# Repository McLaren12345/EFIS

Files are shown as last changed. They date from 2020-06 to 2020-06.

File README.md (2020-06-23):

# EFIS
### Introduction
A STM32 based Primary Flight Display with QT based PC software indicator. Contain PCB files, STM32 project files, QT project files and 3D print models.

本项目为基于STM32的微型姿态仪，包含PCB文件，STM32工程文件，QT工程文件与3D打印外壳文件。

采用陀螺仪传感器MPU6050，气压式高度计BMP180，程序可以显示模块当前的六轴传感器数据与海拔高度，空速与垂直速度等采用模拟积分方法计算求得(也就是惯性导航)。BMP180气压数据采用一阶卡尔曼滤波方法进行平滑。通讯采用NRF21L01无线模块传输，PCB中未画出，仅保留了与模块的接口。

QT部分基于开源项目修改；https://sourceforge.net/projects/qfi/

### Images
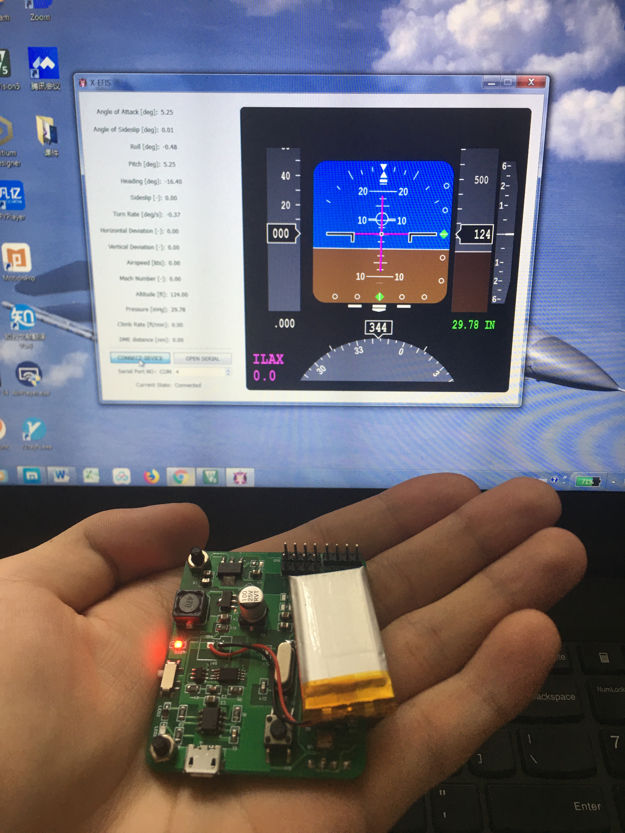
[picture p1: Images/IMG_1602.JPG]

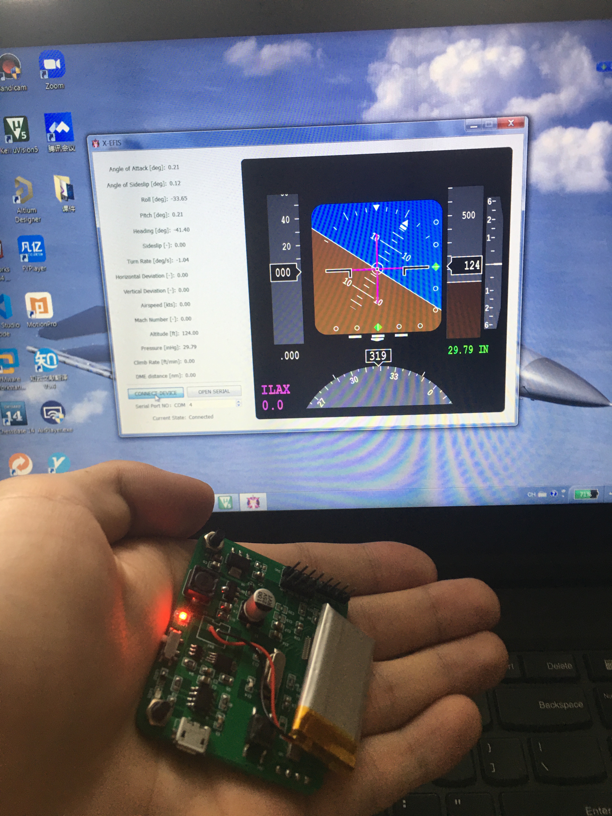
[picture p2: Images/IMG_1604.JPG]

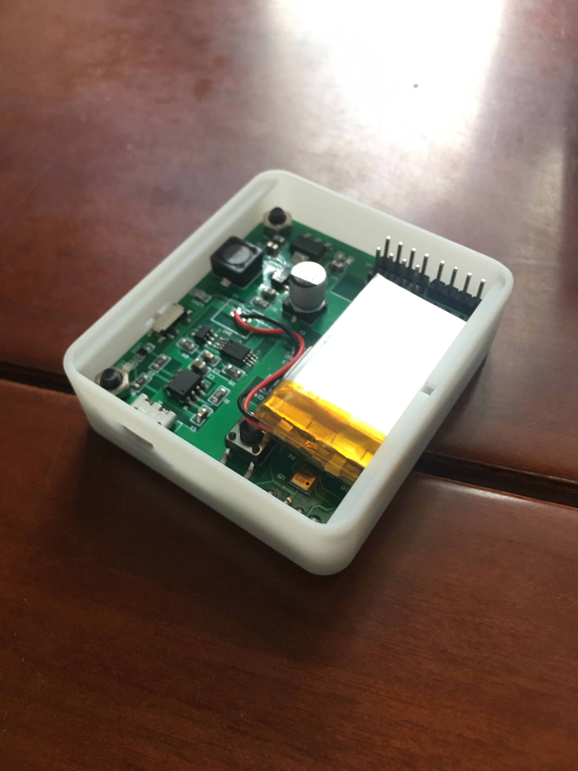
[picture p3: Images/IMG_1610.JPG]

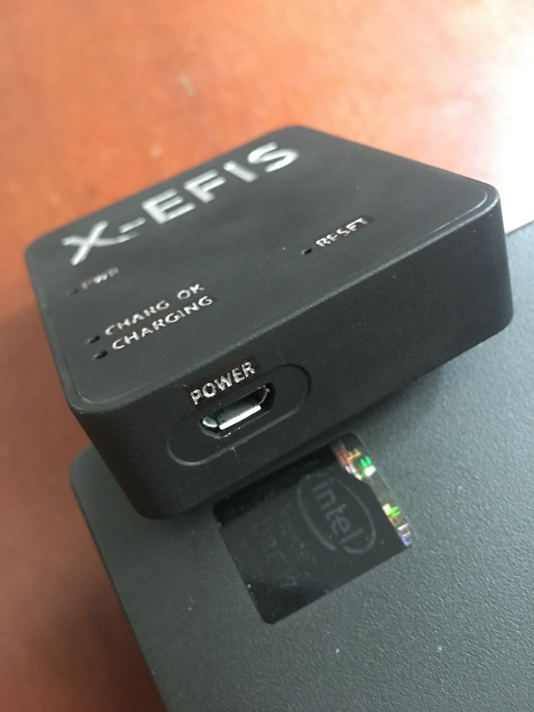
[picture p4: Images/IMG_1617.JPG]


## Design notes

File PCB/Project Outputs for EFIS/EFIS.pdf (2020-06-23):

Comment | Description | Designator | Footprint | LibRef | Quantity
HDR-1X2 | 2P接插件 | BAT | XH2.54-LI-2P | Header 2 | 1
10uf | 贴片电容 | C1, C3, C5, C7, C10, C11, C15, C16, C17, C18, C19, C20 | C 0805_L | C | 12
100uf | 贴片电容 | C2 | C 0805_L | C | 1
0.1uf | 贴片电容 | C4, C6, C8 | C 0805_L | C | 3
104 | 贴片电容 | C9, C12 | C 0805_L | C | 2
22pf | 贴片电容 | C13, C14 | C 0805_L | C | 2
B5919WS | 肖特基二极管 | D1 | SOD-323 | 1N5819 | 1
100uF/16V | 贴片电解电容 | E1 | CM D(6.3*5.4) | CE_SMD | 1
TP4056 | 外置EEPROM | IC1 | SOP8_L | 24Cxx | 1
HDR-1X4 | 4P接插件 | JP2, JP4, JP5, SWD | HDR2.54-LI-4P | Header 4 | 4
47uH | 功率屏蔽电感 | L1 | CDRH73 | L-CDRH | 1
红色 | 贴片LED | LED1, LED3 | LED 0603R | LED-SMD | 2
绿色 | 贴片LED | LED2 | LED 0603G | LED-SMD | 1
1.2K | 贴片电阻 | R1 | R 0805_L | R | 1
1K | 贴片电阻 | R2, R3, R5, R6, R11 | R 0805_L | R | 5
100R | 贴片电阻 | R4 | R 0805_L | R | 1
10R | 贴片电阻 | R7 | R 0805_L | R | 1
10K | 贴片电阻 | R8, R9, R10 | R 0805_L | R | 3
SS-12F23 | 1路波动开关 | S1 | MSK-12C01-07 | SSW-1P | 1
6x6x5 | 贴片6x6轻触开 关 | SW1 | TSW SMD-6*6*5 | TSW SMD-6x6 | 1
STM32F103C8T 6 | STM32 ARM-based 32-bit MCU Performance Line with 64 kB Flash, 20 kB Internal RAM, -40 to +85癈 Temperature, 48-Pin LQFP, Tray | U1 | LQFP48_N | STM32F103C8T 6 | 1
DW01 | 锂电池过流保护 IC | U2 | SOT23-6N | DW01 | 1
GS8205A | N沟道增强型功 率场效应管 | U3 | SSOP8_N | GS8205A | 1
MPU6050 | 三轴加速度+三 轴陀螺仪 | U4 | QFN_24 | MPU6050 | 1
BMP180 | | U5 | LGA7 | BMP180 | 1
USB-5P | 微型USB母座 | USB1 | USB-MICRO_A | USB-5P | 1
AMS1117-3V3 | 三端稳压芯片 | V1 | SOT223_N | AMS1117 | 1
CE8301 | LDO线性稳压芯 片 | V2 | SOT89_N | HT71xx | 1
8MHz | 2脚无源脚晶振 | X1 | OSC HC-49SMD | XTAL-2P | 1

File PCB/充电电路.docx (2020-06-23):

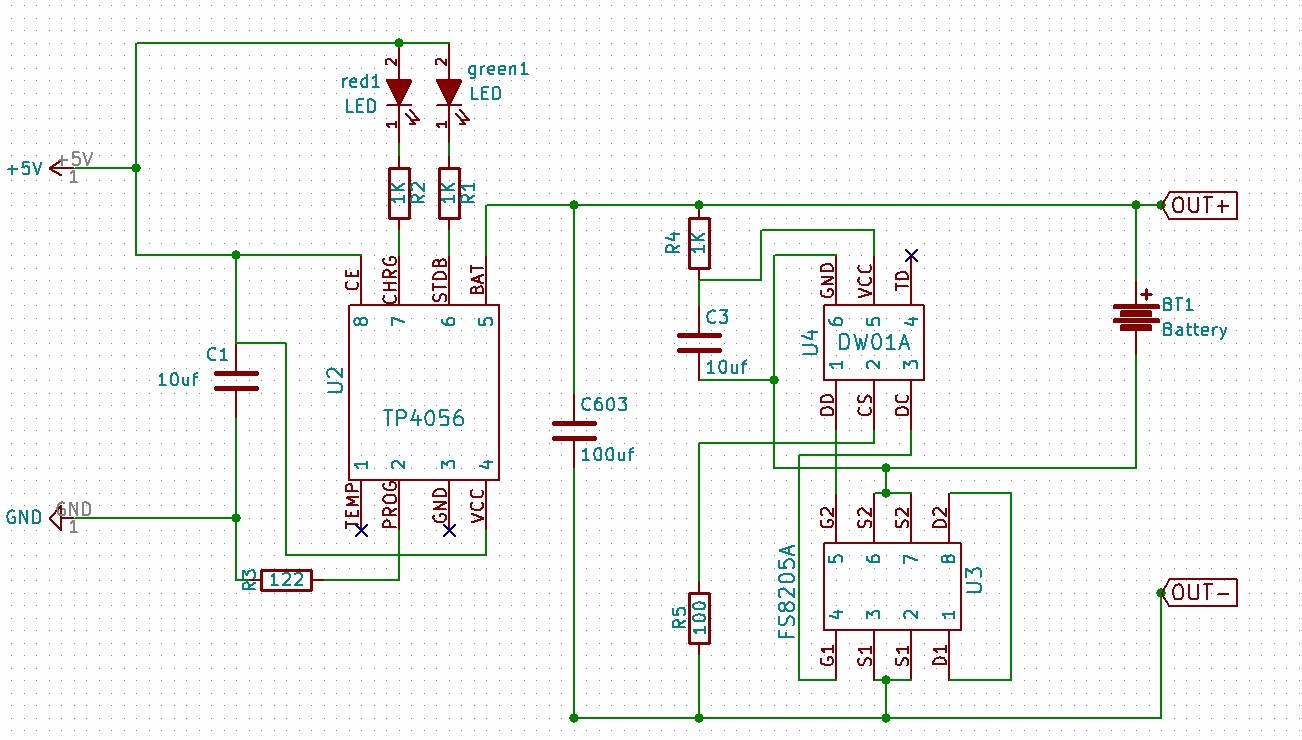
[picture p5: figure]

OUT-要和GND连在一起。R4和R5的值反了，R4是100，R5是1K。

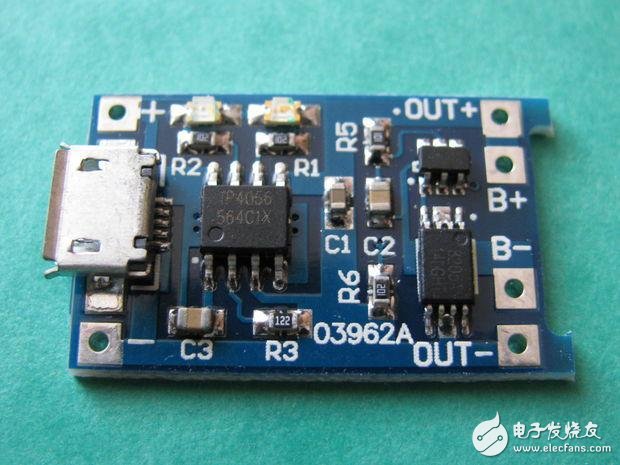
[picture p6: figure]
æ æ æ æ ä½ å ¶ä½ ä¸ ä¸ªç µæ± ä¿ æ ¤ç ¾æ ¿
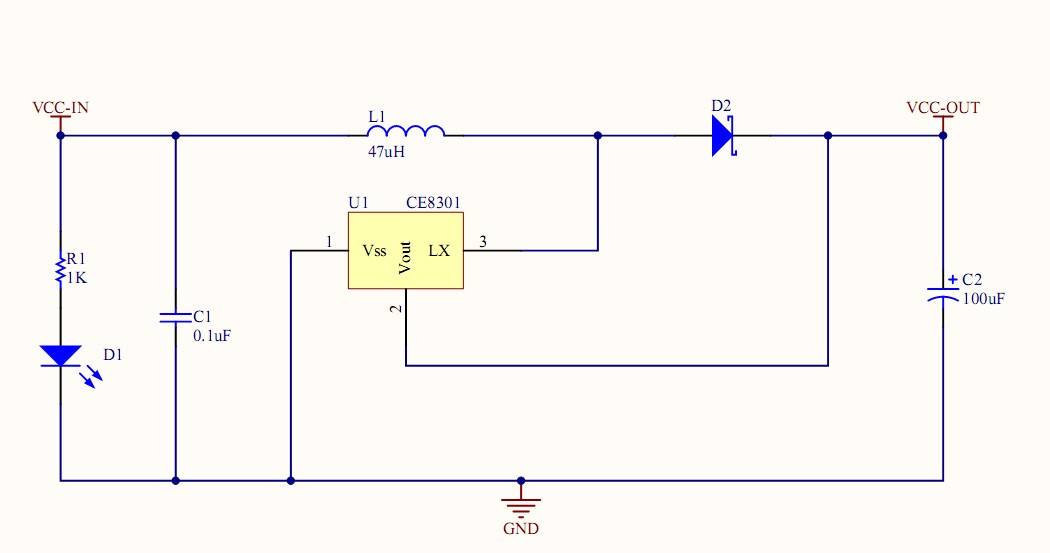
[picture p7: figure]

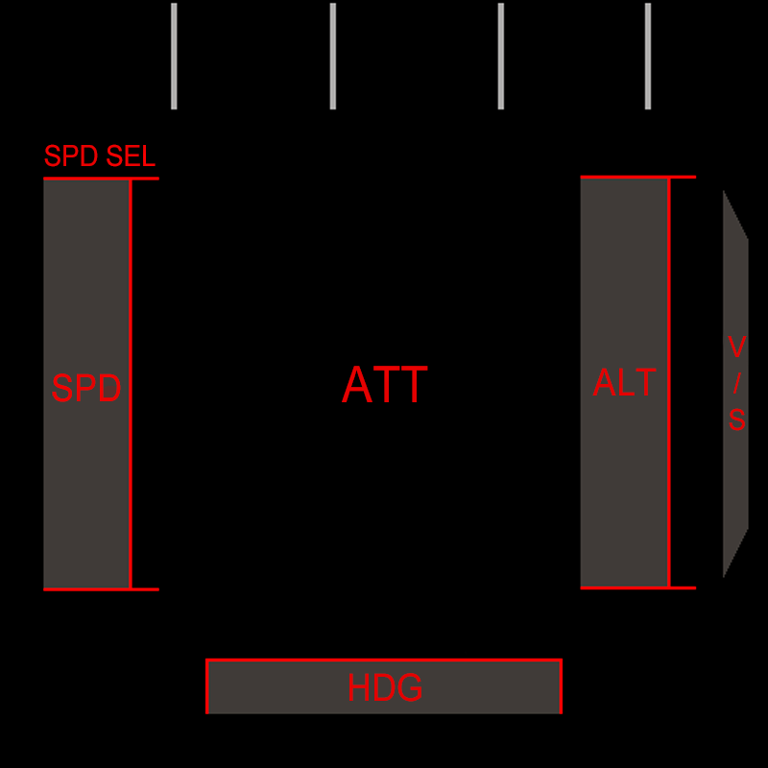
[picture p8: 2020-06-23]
QT/images/pfd/align_pfd-1.png

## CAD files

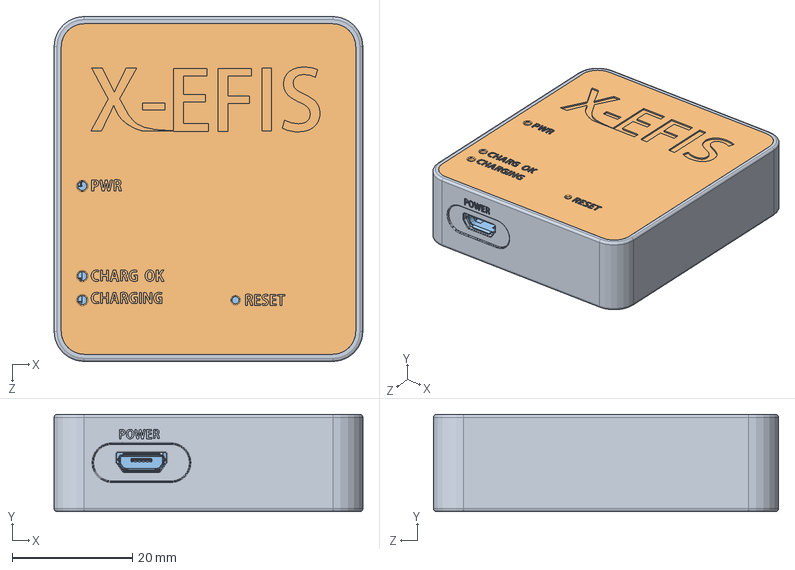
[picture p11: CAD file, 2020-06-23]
EFIS 3D Cover/BOX.SLDASM
51.4 x 16.2 x 57.4 mm
CoverBox
BoxTop
PCB1

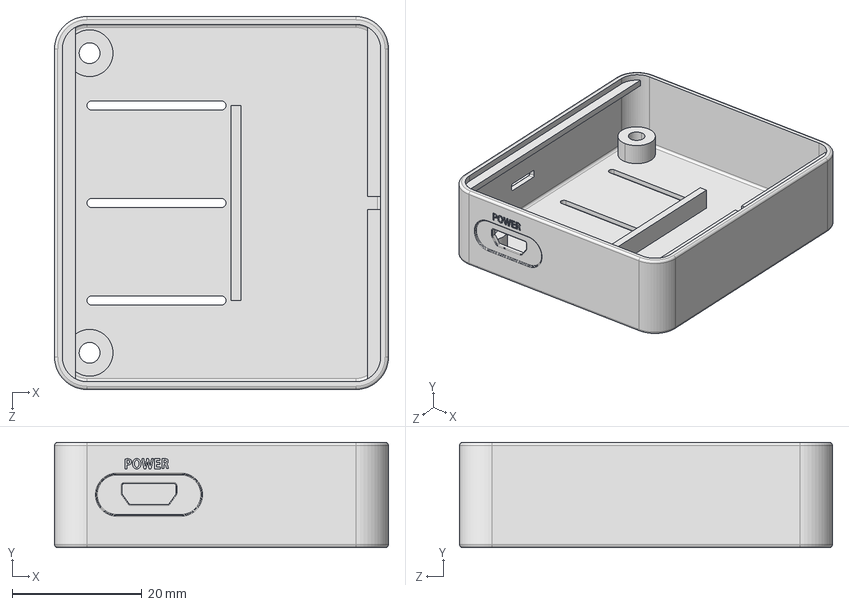
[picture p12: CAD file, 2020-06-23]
EFIS 3D Cover/CoverBox.STEP
51.4 x 16.2 x 57.4 mm

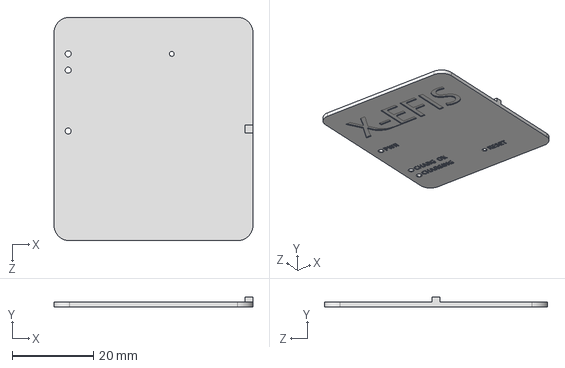
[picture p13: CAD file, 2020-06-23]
EFIS 3D Cover/BoxTop.STEP
49.0 x 2.40 x 55.0 mm

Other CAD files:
EFIS 3D Cover/BoxTop.SLDPRT
EFIS 3D Cover/BoxTop.STL
EFIS 3D Cover/CoverBox.SLDPRT
EFIS 3D Cover/CoverBox.STL

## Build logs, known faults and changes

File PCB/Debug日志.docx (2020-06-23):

Debug日志

1.I2C总线需要上拉电阻，电阻的阻值根据通讯速率选取，如不加数据返回一直为0

2.芯片一直复位：

2.1软件问题：F103芯片的头文件有3种，对应高中小三种flash容量，选错头文件编译出来的程序会跑飞激发硬件看门狗，同样，keil工程的配置也要做相应修改，同时芯片擦写算法尽量选择MDK CORE的算法

2.2硬件问题：1.复位电容击穿，现象为电容的容值为无穷大，相当于电阻为0，直接与GND短接2.助焊膏会吸潮，没有擦干净会导致莫名其妙的问题，应使用酒精等溶剂洗板

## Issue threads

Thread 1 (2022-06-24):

No program X-EFIS

brightproject, 2022-06-24:
Please tell me how to install your code on the stm32 board, as an example F103C8T6
Where did the gui interface x-efis go?
I wanted to try your project, but I can't find the "entry point" to it.

McLaren12345, 2022-06-24:
The STM32 Project is based on Keil IDE, and the project file is located at STM32/USER/MPU6050.uvprojx.
The QT based GUI project file is located at QT/src/example.pro.
It can be easy if your computer have installed these IDE or you need to import the project to other IDE by yourself.

brightproject, 2022-06-24:
There is main.c file?

McLaren12345, 2022-06-25:
yes, the main.c file is also in that path.

------------------ Original ------------------
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

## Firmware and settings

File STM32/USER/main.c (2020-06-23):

#include "led.h"
#include "delay.h"
#include "key.h"
#include "sys.h"
#include "lcd.h"
#include "usart.h"
#include "mpu6050.h"
#include "bmp180.h"
#include "usmart.h"   
#include "inv_mpu.h"
#include "inv_mpu_dmp_motion_driver.h" 

 
/************************************************
 ALIENTEK战舰STM32开发板实验32
 MPU6050六轴传感器 实验
 技术支持：www.openedv.com
 淘宝店铺：http://eboard.taobao.com 
 关注微信公众平台微信号："正点原子"，免费获取STM32资料。
 广州市星翼电子科技有限公司  
 作者：正点原子 @ALIENTEK
************************************************/


//串口1发送1个字符 
//c:要发送的字符
void usart1_send_char(u8 c)
{   	
	while(USART_GetFlagStatus(USART2,USART_FLAG_TC)==RESET); //循环发送,直到发送完毕   
	USART_SendData(USART2,c);  
} 
//传送数据给匿名四轴上位机软件(V2.6版本)
//fun:功能字. 0XA0~0XAF
//data:数据缓存区,最多28字节!!
//len:data区有效数据个数
void usart1_niming_report(u8 fun,u8*data,u8 len)
{
	u8 send_buf[31];
	u8 i;
	if(len>28)return;	//最多28字节数据 
	//send_buf[len+3]=0;	//校验数置零
	send_buf[0]=0X88;	//帧头
	send_buf[1]=fun;	//功能字
	send_buf[2]=len;	//数据长度
	for(i=0;i<len;i++)send_buf[3+i]=data[i];			//复制数据
	//for(i=0;i<len+3;i++)send_buf[len+3]+=send_buf[i];	//计算校验和	
	for(i=0;i<len+3;i++)usart1_send_char(send_buf[i]);	//发送数据到串口1 
}
//发送加速度传感器数据和陀螺仪数据
//aacx,aacy,aacz:x,y,z三个方向上面的加速度值
//gyrox,gyroy,gyroz:x,y,z三个方向上面的陀螺仪值
void mpu6050_send_data(short aacx,short aacy,short aacz,short gyrox,short gyroy,short gyroz)
{
	u8 tbuf[12]; 
	tbuf[0]=(aacx>>8)&0XFF;
	tbuf[1]=aacx&0XFF;
	tbuf[2]=(aacy>>8)&0XFF;
	tbuf[3]=aacy&0XFF;
	tbuf[4]=(aacz>>8)&0XFF;
	tbuf[5]=aacz&0XFF; 
	tbuf[6]=(gyrox>>8)&0XFF;
	tbuf[7]=gyrox&0XFF;
	tbuf[8]=(gyroy>>8)&0XFF;
	tbuf[9]=gyroy&0XFF;
	tbuf[10]=(gyroz>>8)&0XFF;
	tbuf[11]=gyroz&0XFF;
	usart1_niming_report(0XA1,tbuf,12);//自定义帧,0XA1
}	
//通过串口1上报结算后的姿态数据给电脑
//aacx,aacy,aacz:x,y,z三个方向上面的加速度值
//gyrox,gyroy,gyroz:x,y,z三个方向上面的陀螺仪值
//roll:横滚角.单位0.01度。 -18000 -> 18000 对应 -180.00  ->  180.00度
//pitch:俯仰角.单位 0.01度。-9000 - 9000 对应 -90.00 -> 90.00 度
//yaw:航向角.单位为0.1度 0 -> 3600  对应 0 -> 360.0度
void usart1_report_imu(short aacx,short aacy,short aacz,short gyrox,short gyroy,short gyroz,short roll,short pitch,short yaw,short pressure,short altitude)
{
	u8 tbuf[28]; 
	u8 i;
	for(i=0;i<28;i++)tbuf[i]=0;//清0
	tbuf[0]=(aacx>>8)&0XFF;
	tbuf[1]=aacx&0XFF;
	tbuf[2]=(aacy>>8)&0XFF;
	tbuf[3]=aacy&0XFF;
	tbuf[4]=(aacz>>8)&0XFF;
	tbuf[5]=aacz&0XFF; 
	tbuf[6]=(gyrox>>8)&0XFF;
	tbuf[7]=gyrox&0XFF;
	tbuf[8]=(gyroy>>8)&0XFF;
	tbuf[9]=gyroy&0XFF;
	tbuf[10]=(gyroz>>8)&0XFF;
	tbuf[11]=gyroz&0XFF;
	tbuf[12]=(pressure>>8)&0XFF;
	tbuf[13]=pressure&0XFF;
	tbuf[14]=(altitude>>8)&0XFF;
	tbuf[15]=altitude&0XFF;
	tbuf[18]=(roll>>8)&0XFF;
	tbuf[19]=roll&0XFF;
	tbuf[20]=(pitch>>8)&0XFF;
	tbuf[21]=pitch&0XFF;
	tbuf[22]=(yaw>>8)&0XFF;
	tbuf[23]=yaw&0XFF;
	usart1_niming_report(0XAF,tbuf,28);//飞控显示帧,0XAF
	usartreport=0;
}  
 	
 int main(void)
 {	 
	u8 t=3,report=1;			//默认开启上报
//	u8 key;
	float pitch,roll,yaw; 		//欧拉角
	short aacx,aacy,aacz;		//加速度传感器原始数据
	short gyrox,gyroy,gyroz;	//陀螺仪原始数据
//	short temp;					//温度	
	 
	NVIC_PriorityGroupConfig(NVIC_PriorityGroup_2);	 //设置NVIC中断分组2:2位抢占优先级，2位响应优先级
	uart_init(9600);	 	//串口初始化为500000
	delay_init();	//延时初始化 
 
	MPU_Init();					//初始化MPU6050
	 
	BMP_ReadCalibrationData();//读取BMP180

	while(mpu_dmp_init())
 	{

	}  
 
 	while(1)
	{

      
		if(mpu_dmp_get_data(&pitch,&roll,&yaw)==0)
		{ 
			//temp=MPU_Get_Temperature();	//得到温度值
			MPU_Get_Accelerometer(&aacx,&aacy,&aacz);	//得到加速度传感器数据
			MPU_Get_Gyroscope(&gyrox,&gyroy,&gyroz);	//得到陀螺仪数据
			//if(report)mpu6050_send_data(aacx,aacy,aacz,gyrox,gyroy,gyroz);//用自定义帧发送加速度和陀螺仪原始数据
		}
		
		if(t==3)
    {
		  BMP_UncompemstatedToTrue();
			t = 0;
		}
		  t++;
		
    if(usartreport)usart1_report_imu(aacx,aacy,aacz,gyrox,gyroy,gyroz,(int)(roll*100),(int)(pitch*100),(int)(yaw*10),bmp180.pressure_inHg,bmp180.inchALT);
	} 	
}
 

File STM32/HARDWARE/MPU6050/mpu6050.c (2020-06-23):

#include "mpu6050.h"
#include "sys.h"
#include "delay.h"
#include "usart.h"   
//////////////////////////////////////////////////////////////////////////////////	 
//本程序只供学习使用，未经作者许可，不得用于其它任何用途
//ALIENTEK战舰STM32开发板V3
//MPU6050 驱动代码	   
//正点原子@ALIENTEK
//技术论坛:www.openedv.com
//创建日期:2015/1/17
//版本：V1.0
//版权所有，盗版必究。
//Copyright(C) 广州市星翼电子科技有限公司 2009-2019
//All rights reserved									  
////////////////////////////////////////////////////////////////////////////////// 
 
//初始化MPU6050
//返回值:0,成功
//    其他,错误代码
u8 MPU_Init(void)
{ 
	u8 res;
  GPIO_InitTypeDef  GPIO_InitStructure;
	
	RCC_APB2PeriphClockCmd(RCC_APB2Periph_AFIO,ENABLE);//使能AFIO时钟 
	RCC_APB2PeriphClockCmd(RCC_APB2Periph_GPIOA,ENABLE);//先使能外设IO PORTA时钟 
	
  GPIO_InitStructure.GPIO_Pin = GPIO_Pin_15;	 // 端口配置
  GPIO_InitStructure.GPIO_Mode = GPIO_Mode_Out_PP; 		 //推挽输出
  GPIO_InitStructure.GPIO_Speed = GPIO_Speed_50MHz;		 //IO口速度为50MHz
  GPIO_Init(GPIOA, &GPIO_InitStructure);					 //根据设定参数初始化GPIOA

	GPIO_PinRemapConfig(GPIO_Remap_SWJ_JTAGDisable,ENABLE);//禁止JTAG,从而PA15可以做普通IO使用,否则PA15不能做普通IO!!!
	
	MPU_AD0_CTRL=0;			//控制MPU6050的AD0脚为低电平,从机地址为:0X68
	
	MPU_IIC_Init();//初始化IIC总线
	MPU_Write_Byte(MPU_PWR_MGMT1_REG,0X80);	//复位MPU6050
  delay_ms(100);
	MPU_Write_Byte(MPU_PWR_MGMT1_REG,0X00);	//唤醒MPU6050 
	MPU_Set_Gyro_Fsr(3);					//陀螺仪传感器,±2000dps
	MPU_Set_Accel_Fsr(0);					//加速度传感器,±2g
	MPU_Set_Rate(50);						//设置采样率50Hz
	MPU_Write_Byte(MPU_INT_EN_REG,0X00);	//关闭所有中断
	MPU_Write_Byte(MPU_USER_CTRL_REG,0X00);	//I2C主模式关闭
	MPU_Write_Byte(MPU_FIFO_EN_REG,0X00);	//关闭FIFO
	MPU_Write_Byte(MPU_INTBP_CFG_REG,0X80);	//INT引脚低电平有效
	res=MPU_Read_Byte(MPU_DEVICE_ID_REG);
	if(res==MPU_ADDR)//器件ID正确
	{
		MPU_Write_Byte(MPU_PWR_MGMT1_REG,0X01);	//设置CLKSEL,PLL X轴为参考
		MPU_Write_Byte(MPU_PWR_MGMT2_REG,0X00);	//加速度与陀螺仪都工作
		MPU_Set_Rate(50);						//设置采样率为50Hz
 	}else return 1;
	return 0;
}
//设置MPU6050陀螺仪传感器满量程范围
//fsr:0,±250dps;1,±500dps;2,±1000dps;3,±2000dps
//返回值:0,设置成功
//    其他,设置失败 
u8 MPU_Set_Gyro_Fsr(u8 fsr)
{
	return MPU_Write_Byte(MPU_GYRO_CFG_REG,fsr<<3);//设置陀螺仪满量程范围  
}
//设置MPU6050加速度传感器满量程范围
//fsr:0,±2g;1,±4g;2,±8g;3,±16g
//返回值:0,设置成功
//    其他,设置失败 
u8 MPU_Set_Accel_Fsr(u8 fsr)
{
	return MPU_Write_Byte(MPU_ACCEL_CFG_REG,fsr<<3);//设置加速度传感器满量程范围  
}
//设置MPU6050的数字低通滤波器
//lpf:数字低通滤波频率(Hz)
//返回值:0,设置成功
//    其他,设置失败 
u8 MPU_Set_LPF(u16 lpf)
{
	u8 data=0;
	if(lpf>=188)data=1;
	else if(lpf>=98)data=2;
	else if(lpf>=42)data=3;
	else if(lpf>=20)data=4;
	else if(lpf>=10)data=5;
	else data=6; 
	return MPU_Write_Byte(MPU_CFG_REG,data);//设置数字低通滤波器  
}
//设置MPU6050的采样率(假定Fs=1KHz)
//rate:4~1000(Hz)
//返回值:0,设置成功
//    其他,设置失败 
u8 MPU_Set_Rate(u16 rate)
{
	u8 data;
	if(rate>1000)rate=1000;
	if(rate<4)rate=4;
	data=1000/rate-1;
	data=MPU_Write_Byte(MPU_SAMPLE_RATE_REG,data);	//设置数字低通滤波器
 	return MPU_Set_LPF(rate/2);	//自动设置LPF为采样率的一半
}

//得到温度值
//返回值:温度值(扩大了100倍)
short MPU_Get_Temperature(void)
{
    u8 buf[2]; 
    short raw;
	float temp;
	MPU_Read_Len(MPU_ADDR,MPU_TEMP_OUTH_REG,2,buf); 
    raw=((u16)buf[0]<<8)|buf[1];  
    temp=36.53+((double)raw)/340;  
    return temp*100;;
}
//得到陀螺仪值(原始值)
//gx,gy,gz:陀螺仪x,y,z轴的原始读数(带符号)
//返回值:0,成功
//    其他,错误代码
u8 MPU_Get_Gyroscope(short *gx,short *gy,short *gz)
{
    u8 buf[6],res;  
	res=MPU_Read_Len(MPU_ADDR,MPU_GYRO_XOUTH_REG,6,buf);
	if(res==0)
	{
		*gx=((u16)buf[0]<<8)|buf[1];  
		*gy=((u16)buf[2]<<8)|buf[3];  
		*gz=((u16)buf[4]<<8)|buf[5];
	} 	
    return res;;
}
//得到加速度值(原始值)
//gx,gy,gz:陀螺仪x,y,z轴的原始读数(带符号)
//返回值:0,成功
//    其他,错误代码
u8 MPU_Get_Accelerometer(short *ax,short *ay,short *az)
{
    u8 buf[6],res;  
	res=MPU_Read_Len(MPU_ADDR,MPU_ACCEL_XOUTH_REG,6,buf);
	if(res==0)
	{
		*ax=((u16)buf[0]<<8)|buf[1];  
		*ay=((u16)buf[2]<<8)|buf[3];  
		*az=((u16)buf[4]<<8)|buf[5];
	} 	
    return res;;
}
//IIC连续写
//addr:器件地址 
//reg:寄存器地址
//len:写入长度
//buf:数据区
//返回值:0,正常
//    其他,错误代码
u8 MPU_Write_Len(u8 addr,u8 reg,u8 len,u8 *buf)
{
	u8 i; 
    MPU_IIC_Start(); 
	MPU_IIC_Send_Byte((addr<<1)|0);//发送器件地址+写命令	
	if(MPU_IIC_Wait_Ack())	//等待应答
	{
		MPU_IIC_Stop();		 
		return 1;		
	}
    MPU_IIC_Send_Byte(reg);	//写寄存器地址
    MPU_IIC_Wait_Ack();		//等待应答
	for(i=0;i<len;i++)
	{
		MPU_IIC_Send_Byte(buf[i]);	//发送数据
		if(MPU_IIC_Wait_Ack())		//等待ACK
		{
			MPU_IIC_Stop();	 
			return 1;		 
		}		
	}    
    MPU_IIC_Stop();	 
	return 0;	
} 
//IIC连续读
//addr:器件地址
//reg:要读取的寄存器地址
//len:要读取的长度
//buf:读取到的数据存储区
//返回值:0,正常
//    其他,错误代码
u8 MPU_Read_Len(u8 addr,u8 reg,u8 len,u8 *buf)
{ 
 	MPU_IIC_Start(); 
	MPU_IIC_Send_Byte((addr<<1)|0);//发送器件地址+写命令	
	if(MPU_IIC_Wait_Ack())	//等待应答
	{
		MPU_IIC_Stop();		 
		return 1;		
	}
    MPU_IIC_Send_Byte(reg);	//写寄存器地址
    MPU_IIC_Wait_Ack();		//等待应答
    MPU_IIC_Start();
	MPU_IIC_Send_Byte((addr<<1)|1);//发送器件地址+读命令	
    MPU_IIC_Wait_Ack();		//等待应答 
	while(len)
	{
		if(len==1)*buf=MPU_IIC_Read_Byte(0);//读数据,发送nACK 
		else *buf=MPU_IIC_Read_Byte(1);		//读数据,发送ACK  
		len--;
		buf++; 
	}    
    MPU_IIC_Stop();	//产生一个停止条件 
	return 0;	
}
//IIC写一个字节 
//reg:寄存器地址
//data:数据
//返回值:0,正常
//    其他,错误代码
u8 MPU_Write_Byte(u8 reg,u8 data) 				 
{ 
    MPU_IIC_Start(); 
	MPU_IIC_Send_Byte((MPU_ADDR<<1)|0);//发送器件地址+写命令	
	if(MPU_IIC_Wait_Ack())	//等待应答
	{
		MPU_IIC_Stop();		 
		return 1;		
	}
    MPU_IIC_Send_Byte(reg);	//写寄存器地址
    MPU_IIC_Wait_Ack();		//等待应答 
	MPU_IIC_Send_Byte(data);//发送数据
	if(MPU_IIC_Wait_Ack())	//等待ACK
	{
		MPU_IIC_Stop();	 
		return 1;		 
	}		 
    MPU_IIC_Stop();	 
	return 0;
}
//IIC读一个字节 
//reg:寄存器地址 
//返回值:读到的数据
u8 MPU_Read_Byte(u8 reg)
{
	u8 res;
    MPU_IIC_Start(); 
	MPU_IIC_Send_Byte((MPU_ADDR<<1)|0);//发送器件地址+写命令	
	MPU_IIC_Wait_Ack();		//等待应答 
    MPU_IIC_Send_Byte(reg);	//写寄存器地址
    MPU_IIC_Wait_Ack();		//等待应答
    MPU_IIC_Start();
	MPU_IIC_Send_Byte((MPU_ADDR<<1)|1);//发送器件地址+读命令	
    MPU_IIC_Wait_Ack();		//等待应答 
	res=MPU_IIC_Read_Byte(0);//读取数据,发送nACK 
    MPU_IIC_Stop();			//产生一个停止条件 
	return res;		
}

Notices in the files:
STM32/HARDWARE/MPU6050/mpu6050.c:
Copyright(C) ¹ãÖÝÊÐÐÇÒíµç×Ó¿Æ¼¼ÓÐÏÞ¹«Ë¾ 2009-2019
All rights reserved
